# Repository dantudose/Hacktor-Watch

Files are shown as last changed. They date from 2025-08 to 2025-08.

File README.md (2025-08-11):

# Hacktor-Watch 2.0

Open-source power for apps, AI, and fearless hardware hacking!
Why just wear a smartwatch when you can hack it? Hacktor Watch 2.0 is your open-source playground on the wrist — powered by the dual-core ESP32-S3 with Wi-Fi and Bluetooth, rocking a bright 1.28" touch display, and loaded with goodies like a 6-axis IMU, mic, speaker, haptics, and fuel gauge. You get 32MB flash, 8MB PSRAM, USB-C charging, and a 200mAh LiPo to keep your creations running. Whether you’re building custom apps in Arduino or ESP-IDF, training tiny AI models, or turning it into a wearable IoT gadget, this is a smartwatch that’s down for any experiment you throw at it. 

And yes — it’s also sleek and stylish, so no matter how good or bad your code is, it will always look great on your wrist!

<div style='float:center'>
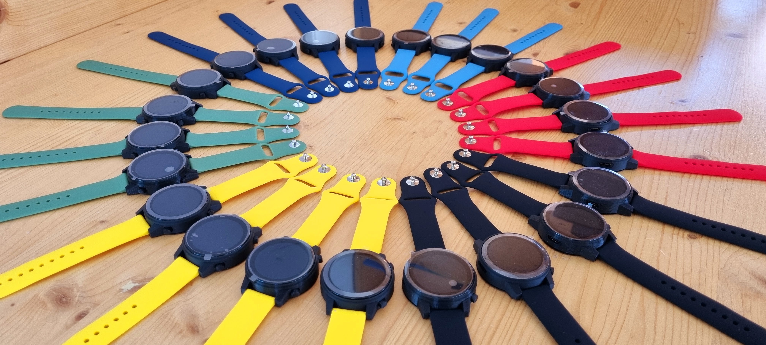
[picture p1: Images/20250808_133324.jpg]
   
  </div>

## Hardware Diagram &amp; features

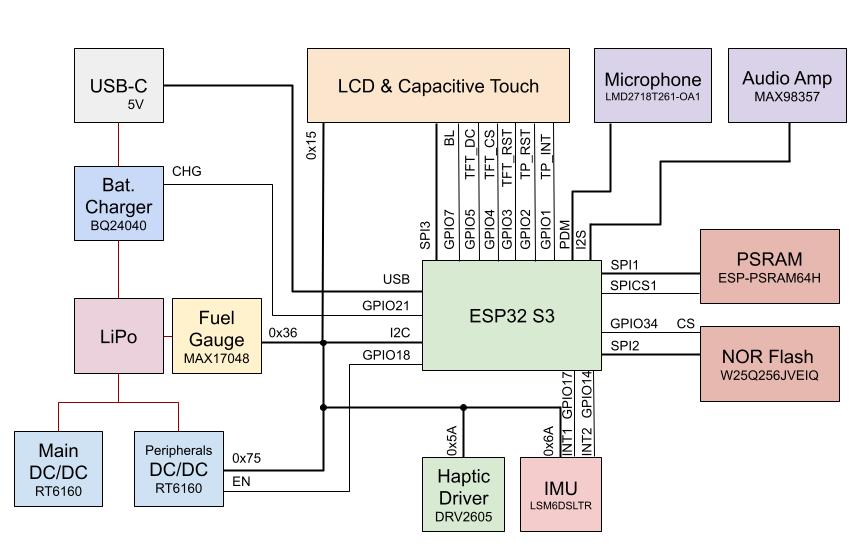
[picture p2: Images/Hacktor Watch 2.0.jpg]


<a href="https://docs.google.com/drawings/d/1u0_o-W6L3w2xveMWQQGLrzZhusZ90oDN8ES3exkrWA4/edit?usp=sharing">Hardware diagram.</a>

This is a open-hardware wearable based on the ESP32 microcontroller. It is fully Arduino-compatible and it comes with the following features:
* <a href="https://www.espressif.com/sites/default/files/documentation/esp32-s3_datasheet_en.pdf">ESP32-S3</a> processor (dual-core 240MHz, WiFI, BLE, 512kB SRAM and 4MB Flash)
* <a href="https://www.aliexpress.com/item/1005007293053050.html">GC9A01</a> 1.28 inch color LCD, 240 x 240 pixels with CST816T capacitive touch screen
* <a href="https://www.st.com/en/mems-and-sensors/lsm6dsl.html">LSM6DSLTR</a> 6-axis inertial sensor (accelerometer and gyroscope)
* <a href="https://www.winbond.com/hq/product/code-storage-flash-memory/serial-nor-flash/?__locale=en&partNo=W25Q256JV">W25Q256JVEIQ</a> 32MB external SPI Flash
* <a href="https://cdn-shop.adafruit.com/product-files/4677/4677_esp-psram64_esp-psram64h_datasheet_en.pdf">ESP-PSRAM64H</a> 8MB PSRAM
* <a href="https://www.ti.com/product/DRV2605/part-details/DRV2605YZFR">DRV2605YZFR</a> haptic driver
* <a href="https://jlcpcb.com/api/file/downloadByFileSystemAccessId/8586212537977618432">LMD2718T261-OA1</a> microphone
* <a href="https://www.analog.com/media/en/technical-documentation/data-sheets/max98357a-max98357b.pdf">MAX98357</a> I2S audio amplifier and speaker
* <a href="https://www.analog.com/media/en/technical-documentation/data-sheets/max17048-max17049.pdf">MAX17048</a> fuel gauge
* Dual <a href="https://www.richtek.com/m/Products/Switching%20Regulators/Buck-Boost%20Converter/RT6160A?sc_lang=en">RT6160</a> DC/DC PMIC (main power and peripherals)
* <a href="https://www.ti.com/lit/ds/symlink/bq24040.pdf?ts=1754753213993">BQ24040</a> LiPo charger
* 200mAh LiPo battery
* USB-C connector for charging and data

<div id="cover">
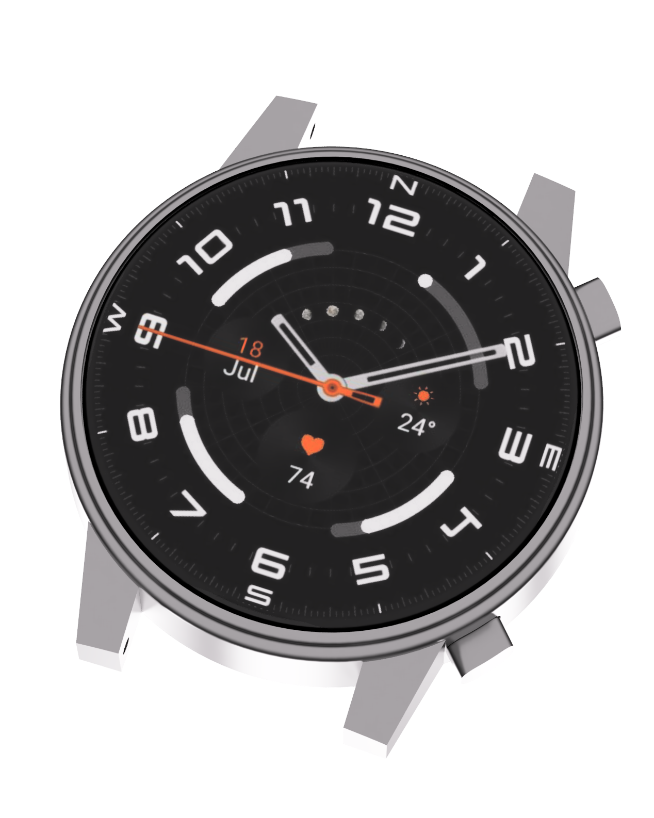
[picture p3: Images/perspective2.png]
   
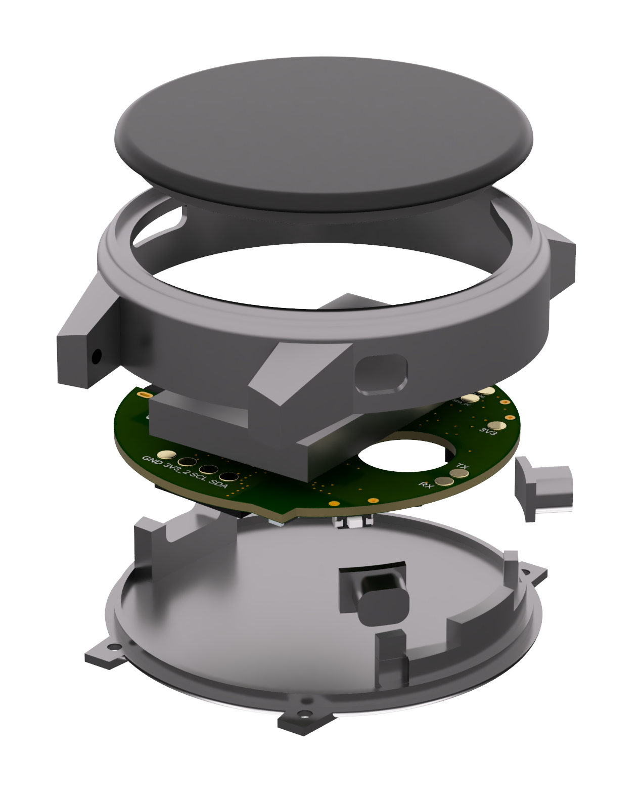
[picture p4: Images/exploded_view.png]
  
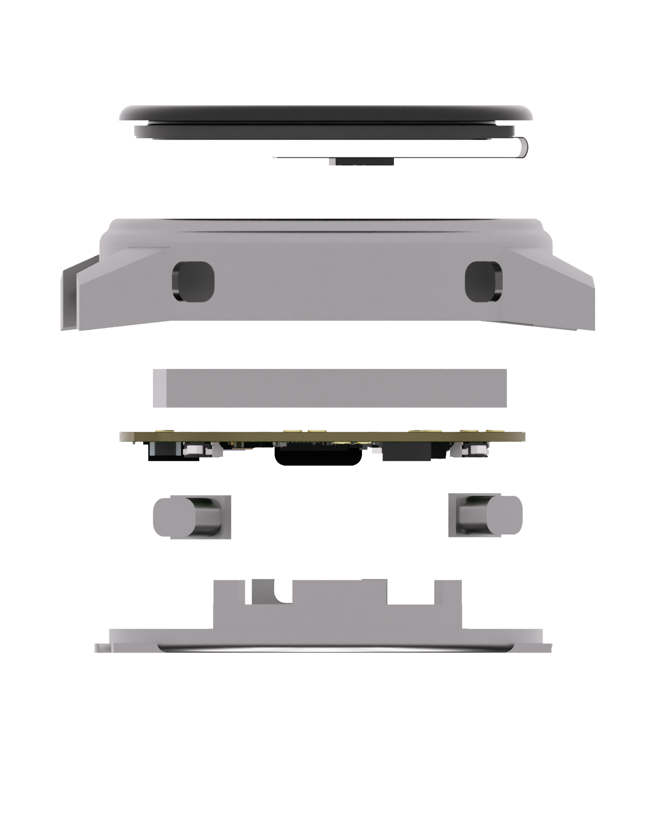
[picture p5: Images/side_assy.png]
   
</div>

## Repository Contents

* **/Hardware** - Schematic and hardware design files (Fusion360 & KiCAD)
* **/Images** - Images & diagrams
* **/Mechanical** - 3D files for the watch case

### Button Layout

 <div style='float:left'>
<table>
<thead>
  <tr>
    <th>Button</th>
    <th>ESP32 Pin</th>
  </tr></thead>
  <tbody>
  <tr>
    <td>BOOT</td>
    <td>IO0</td>
  </tr>
  <tr>
    <td>RESET</td>
    <td>EN</td>
  </tr>
  </tbody>
</table>
 </div>
<div style='float:right'>
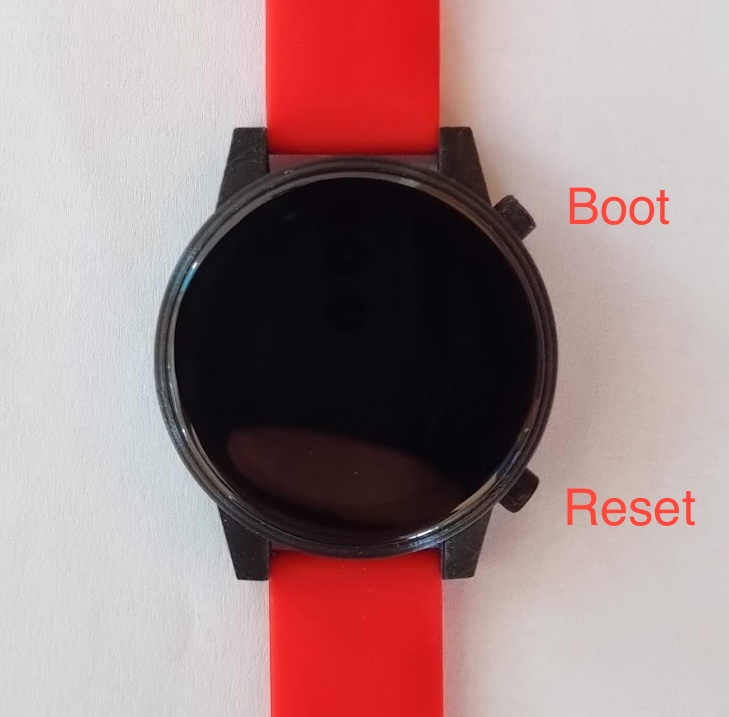
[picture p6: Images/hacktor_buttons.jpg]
   
  </div>

## Software Support
The watch supports Arduino and ESP-IDF programming. For a working NuttX port, check out <a href="https://github.com/radupascale/hectorwatch-nuttx">Radu Pascale's</a> repo. 

## License Information

HW design by <a href="https://github.com/radupascale">Radu Pascale</a>.

This product is _**open source**_! 

Please review the LICENSE file for license information. 

Distributed as-is; no warranty is given.

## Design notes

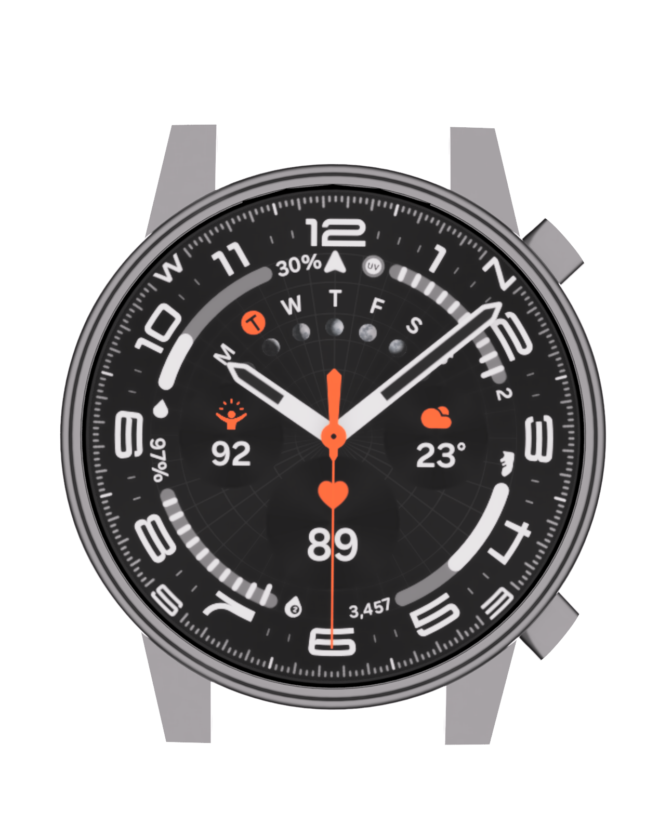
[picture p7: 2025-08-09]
Images/front_view.png

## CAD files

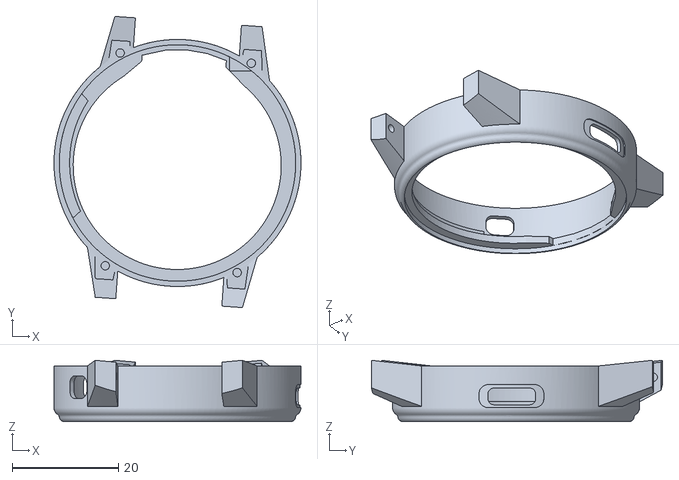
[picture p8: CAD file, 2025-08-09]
Mechanical/main_body.stl
46.5 x 54.8 x 11.6

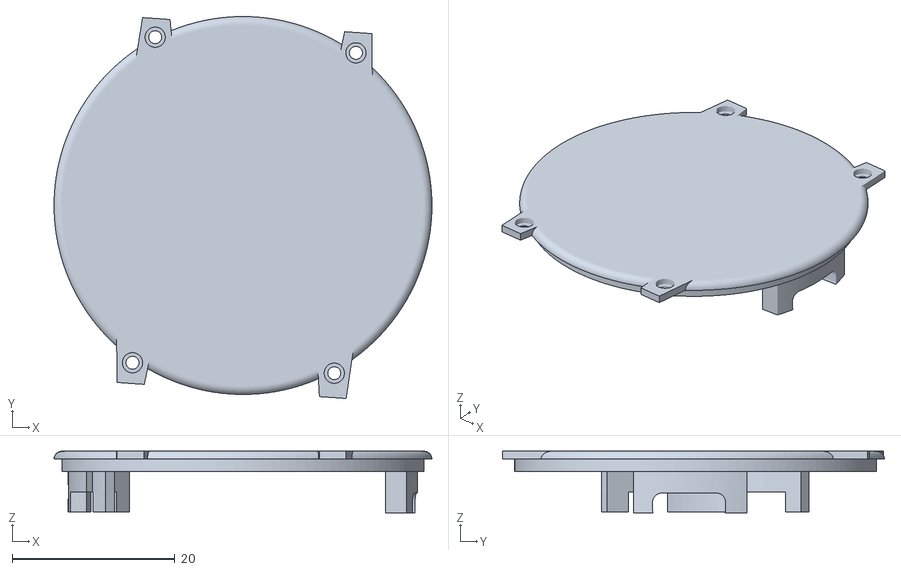
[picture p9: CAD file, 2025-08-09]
Mechanical/bottom_lid.stl
46.5 x 47.0 x 7.60

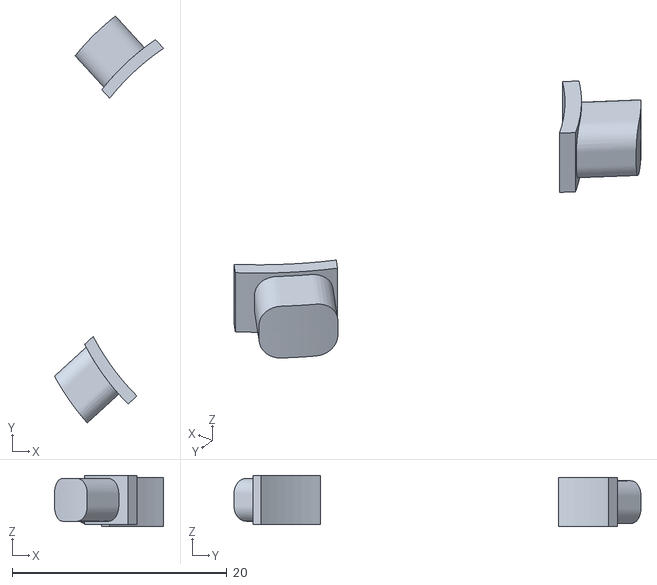
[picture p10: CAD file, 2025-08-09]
Mechanical/button_pushers.stl
10.2 x 37.9 x 4.78

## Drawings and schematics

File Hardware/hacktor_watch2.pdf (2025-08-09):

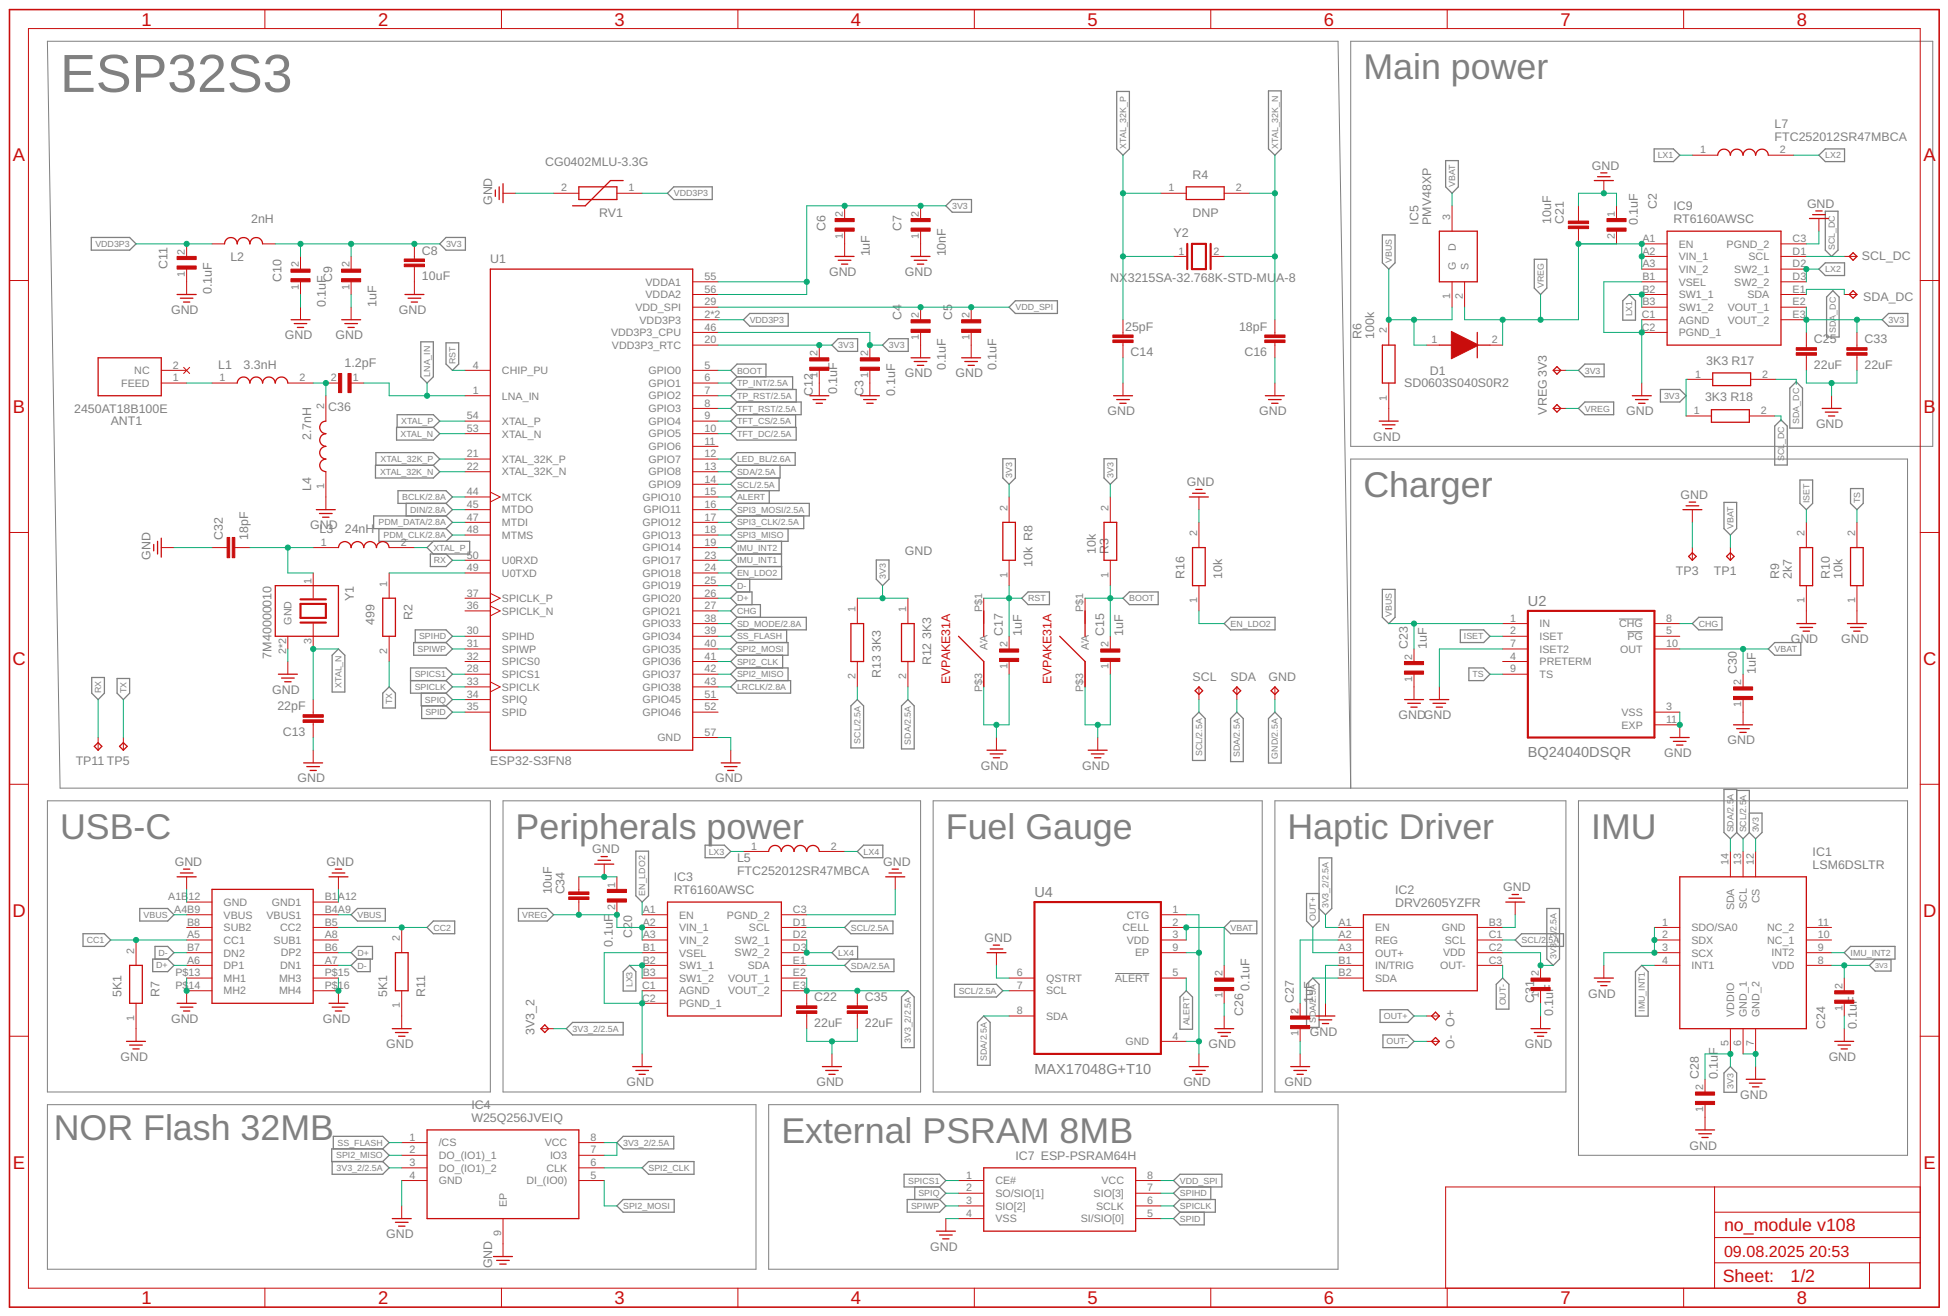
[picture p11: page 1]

XTAL_P | TFT_CS/2.5A 10 GPIO6
XTAL_N | TFT_DC/2.5A

XTAL_32K_P | LED_BL/2.6A 13 GPIO9

35 SPID | 52

SPIQ | SPIHD 6 SI/SIO[0] 5

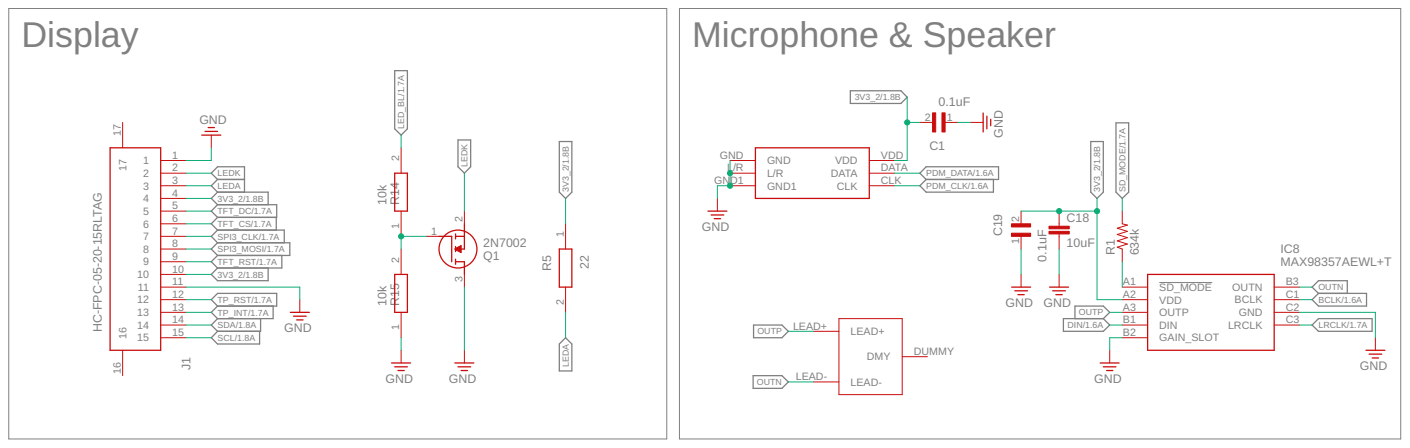
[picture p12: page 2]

0.1uF GND GND GND GND

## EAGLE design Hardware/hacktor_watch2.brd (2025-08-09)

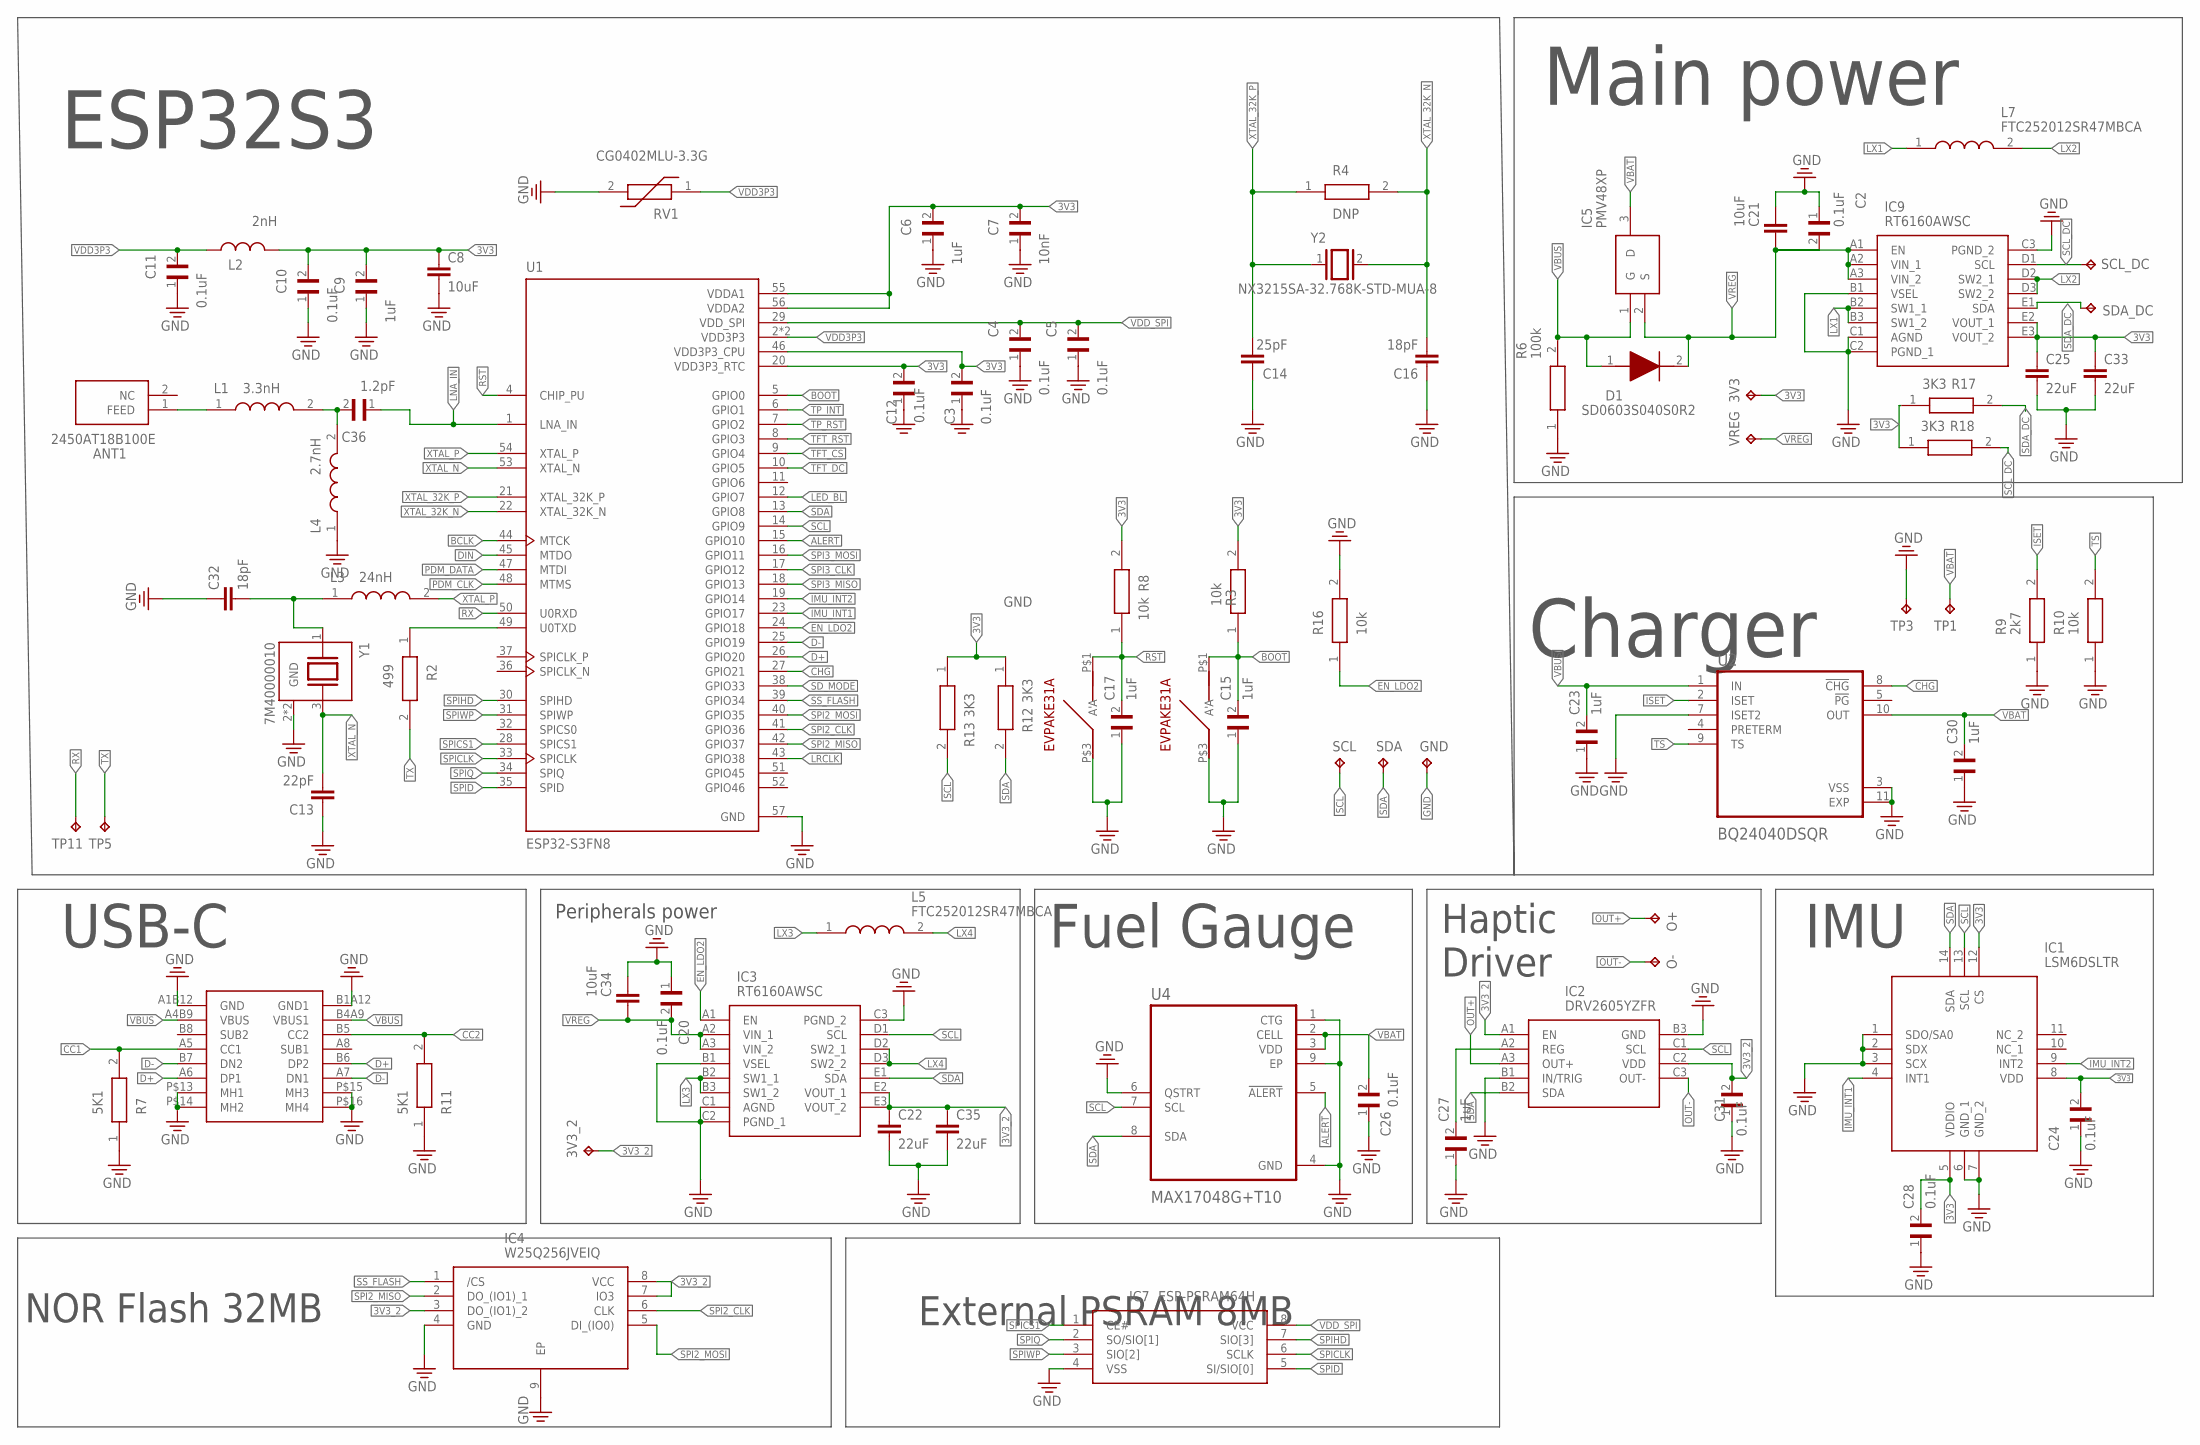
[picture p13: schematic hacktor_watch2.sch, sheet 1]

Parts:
3V3, 3V3_2: TPTP20R; TP20R
ANT1: 2450AT18B100E; ANTC3216X140N
C2, C3, C4, C5, C10, C11, C12, C20, C24, C26, C28, C31: 0.1uF; 0201
C6, C9, C15, C17, C23, C27, C30: 1uF; 0201
C7: 10nF; 0201
C8, C21, C34: 10uF; 0402
C13: 22pF; 0402
C14: 25pF; 0402
C16, C32: 18pF; 0402
C22, C25, C33, C35: 22uF; 0402
C36: 1.2pF; 0201
D1: SD0603S040S0R2; SD0603
GND: TPTP20R; TP20R
IC1: LSM6DSLTR
IC2: DRV2605YZFR; BGA9C50P3X3_144X144X62
IC3, IC9: RT6160AWSC; BGA15C40P3X5_140X230X60
IC4: W25Q256JVEIQ; SON127P800X600X80-9N
IC5: PMV48XP; SOT95P230X110-3N
IC7: ESP-PSRAM64H; SOIC127P600X175-8N
L1: 3.3nH; LQP15MN10NG02D
L2: 2nH; INDC1006X60N
L3: 24nH; LQP15MN10NG02D
L4: 2.7nH; LQP15MN10NG02D
L5, L7: FTC252012SR47MBCA; INDC2016X100N
O+: TPTP20R; TP20R
O-: TPTP20R; TP20R
R2: 499; 0201
R3, R8, R10, R16: 10k; 0201
R4: DNP; 0201
R6: 100k; 0201
R7, R11: 5K1; 0201
R9: 2k7; 0201
R12, R13, R17, R18: 3K3; 0201
RV1: CG0402MLU-3.3G; VARC1005X41N
SCL: TPTP20R; TP20R
SCL_DC: TPTP20R; TP20R
SDA: TPTP20R; TP20R
SDA_DC: TPTP20R; TP20R
TP1, TP3, TP5, TP11: TPTP20R; TP20R
U1: ESP32-S3FN8; QFN40P700X700X90-57N
U2: BQ24040DSQR; SON40P200X200X80-11N
U4: MAX17048G+T10; SON50P200X200X80-9N
U$1, U$3: EVPAKE31A
U$5: TYPE-C16PCB0.8073
VREG: TPTP20R; TP20R
Y1: 7M40000010; XTAL_7M40000010
Y2: NX3215SA-32.768K-STD-MUA-8; XTAL_NX3215SA-32.768K-STD-MUA-8

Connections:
3V3: 3V3.TP, C3.2, C6.2, C7.2, C8.1, C9.2, C10.2, C12.2, C24.2, C25.1, C28.2, C33.1, IC1.5 (VDDIO), IC1.8 (VDD), IC1.12 (CS), IC9.E2 (VOUT_1), IC9.E3 (VOUT_2), L2.2, R3.2, R8.2, R12.1, R13.1, R17.1, R18.1, U1.20 (VDD3P3_RTC), U1.46 (VDD3P3_CPU), U1.55 (VDDA1), U1.56 (VDDA2)
3V3_2: 3V3_2.TP, C22.1, C31.2, C35.1, IC2.A1 (EN), IC2.C2 (VDD), IC3.E2 (VOUT_1), IC3.E3 (VOUT_2), IC4.3 (DO_(IO1)_2), IC4.7 (IO3), IC4.8 (VCC); also elsewhere on the board
ALERT: U1.15 (GPIO10), U4.5 (!ALERT)
BCLK: U1.44 (MTCK); also elsewhere on the board
BOOT: C15.2, R3.1, U1.5 (GPIO0), U$1.P$1 (A)
CC1: R7.2, U$5.A5 (CC1)
CC2: R11.2, U$5.B5 (CC2)
CHG: U1.27 (GPIO21), U2.8 (!CHG)
D+: U1.26 (GPIO20), U$5.A6 (DP1), U$5.B6 (DP2)
D-: U1.25 (GPIO19), U$5.A7 (DN1), U$5.B7 (DN2)
DIN: U1.45 (MTDO); also elsewhere on the board
EN_LDO2: IC3.A1 (EN), R16.1, U1.24 (GPIO18)
GND: C2.1, C3.1, C4.1, C5.1, C6.1, C7.1, C8.2, C9.1, C10.1, C11.1, C12.1, C13.1, C14.1, C15.1, C16.1, C17.1, C20.1, C21.1, C22.2, C23.1, C24.1, C25.2, C26.1, C27.1, C28.1, C30.1, C31.1, C32.1, C33.2, C34.1, C35.2, GND.TP, IC1.1 (SDO/SA0), IC1.2 (SDX), IC1.3 (SCX), IC1.6 (GND_1), IC1.7 (GND_2), IC2.B1 (IN/TRIG), IC2.B3 (GND), IC3.B1 (VSEL), IC3.C1 (AGND), IC3.C2 (PGND_1), IC3.C3 (PGND_2), IC4.4 (GND), IC4.9 (EP), IC7.4 (VSS), IC9.B1 (VSEL), IC9.C1 (AGND), IC9.C2 (PGND_1), IC9.C3 (PGND_2), L4.1, R6.1, R7.1, R9.1, R10.1, R11.1, R16.2, RV1.2, TP3.TP, U1.57 (GND), U2.3 (VSS), U2.7 (ISET2), U2.11 (EXP), U4.1 (CTG), U4.4 (GND), U4.6 (QSTRT), U4.9 (EP), U$1.P$3 (A'), U$3.P$3 (A'), U$5.A1B12 (GND), U$5.B1A12 (GND1), U$5.P$13 (MH1), U$5.P$14 (MH2), U$5.P$15 (MH3), U$5.P$16 (MH4), Y1.2 (GND), Y1.4 (GND); also elsewhere on the board
IMU_INT1: IC1.4 (INT1), U1.23 (GPIO17)
IMU_INT2: IC1.9 (INT2), U1.19 (GPIO14)
ISET: R9.2, U2.2 (ISET)
LED_BL: U1.12 (GPIO7); also elsewhere on the board
LNA_IN: C36.1, U1.1 (LNA_IN)
LRCLK: U1.43 (GPIO38); also elsewhere on the board
LX1: IC9.B2 (SW1_1), IC9.B3 (SW1_2), L7.1
LX2: IC9.D2 (SW2_1), IC9.D3 (SW2_2), L7.2
LX3: IC3.B2 (SW1_1), IC3.B3 (SW1_2), L5.1
LX4: IC3.D2 (SW2_1), IC3.D3 (SW2_2), L5.2
unnamed: C32.2, L3.1, Y1.1
unnamed: ANT1.1 (FEED), L1.1
unnamed: C36.2, L1.2, L4.2
unnamed: R2.1, U1.49 (U0TXD)
unnamed: C27.2, IC2.A2 (REG)
OUT+: IC2.A3 (OUT+), O+.TP
OUT-: IC2.C3 (OUT-), O-.TP
PDM_CLK: U1.48 (MTMS); also elsewhere on the board
PDM_DATA: U1.47 (MTDI); also elsewhere on the board
RST: C17.2, R8.1, U1.4 (CHIP_PU), U$3.P$1 (A)
RX: TP11.TP, U1.50 (U0RXD)
SCL: IC1.13 (SCL), IC2.C1 (SCL), IC3.D1 (SCL), R13.2, SCL.TP, U1.14 (GPIO9), U4.7 (SCL); also elsewhere on the board
SCL_DC: IC9.D1 (SCL), R18.2, SCL_DC.TP
SDA: IC1.14 (SDA), IC2.B2 (SDA), IC3.E1 (SDA), R12.2, SDA.TP, U1.13 (GPIO8), U4.8 (SDA); also elsewhere on the board
SDA_DC: IC9.E1 (SDA), R17.2, SDA_DC.TP
SD_MODE: U1.38 (GPIO33); also elsewhere on the board
SPI2_CLK: IC4.6 (CLK), U1.41 (GPIO36)
SPI2_MISO: IC4.2 (DO_(IO1)_1), U1.42 (GPIO37)
SPI2_MOSI: IC4.5 (DI_(IO0)), U1.40 (GPIO35)
SPI3_CLK: U1.17 (GPIO12); also elsewhere on the board
SPI3_MISO: U1.18 (GPIO13)
SPI3_MOSI: U1.16 (GPIO11); also elsewhere on the board
SPICLK: IC7.6 (SCLK), U1.33 (SPICLK)
SPICS1: IC7.1 (CE#), U1.28 (SPICS1)
SPID: IC7.5 (SI/SIO[0]), U1.35 (SPID)
SPIHD: IC7.7 (SIO[3]), U1.30 (SPIHD)
SPIQ: IC7.2 (SO/SIO[1]), U1.34 (SPIQ)
SPIWP: IC7.3 (SIO[2]), U1.31 (SPIWP)
SS_FLASH: IC4.1 (/CS), U1.39 (GPIO34)
TFT_CS: U1.9 (GPIO4); also elsewhere on the board
TFT_DC: U1.10 (GPIO5); also elsewhere on the board
TFT_RST: U1.8 (GPIO3); also elsewhere on the board
TP_INT: U1.6 (GPIO1); also elsewhere on the board
TP_RST: U1.7 (GPIO2); also elsewhere on the board
TS: R10.2, U2.9 (TS)
TX: R2.2, TP5.TP
VBAT: C26.2, C30.2, IC5.3 (D), TP1.TP, U2.10 (OUT), U4.2 (CELL), U4.3 (VDD)
VBUS: C23.2, D1.1 (A), IC5.1 (G), R6.2, U2.1 (IN), U$5.A4B9 (VBUS), U$5.B4A9 (VBUS1)
VDD3P3: C11.2, L2.1, RV1.1, U1.2 (VDD3P3), U1.3 (VDD3P3)
VDD_SPI: C4.2, C5.2, IC7.8 (VCC), U1.29 (VDD_SPI)
VREG: C2.2, C20.2, C21.2, C34.2, D1.2 (K), IC3.A2 (VIN_1), IC3.A3 (VIN_2), IC5.2 (S), IC9.A1 (EN), IC9.A2 (VIN_1), IC9.A3 (VIN_2), VREG.TP
XTAL_32K_N: C16.2, R4.2, U1.22 (XTAL_32K_N), Y2.2
XTAL_32K_P: C14.2, R4.1, U1.21 (XTAL_32K_P), Y2.1
XTAL_N: C13.2, U1.53 (XTAL_N), Y1.3 (2)
XTAL_P: L3.2, U1.54 (XTAL_P)

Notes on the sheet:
ESP32S3
Main power
Charger
USB-C
Peripherals power
Fuel Gauge
IMU
Haptic Driver
NOR Flash 32MB
External PSRAM 8MB

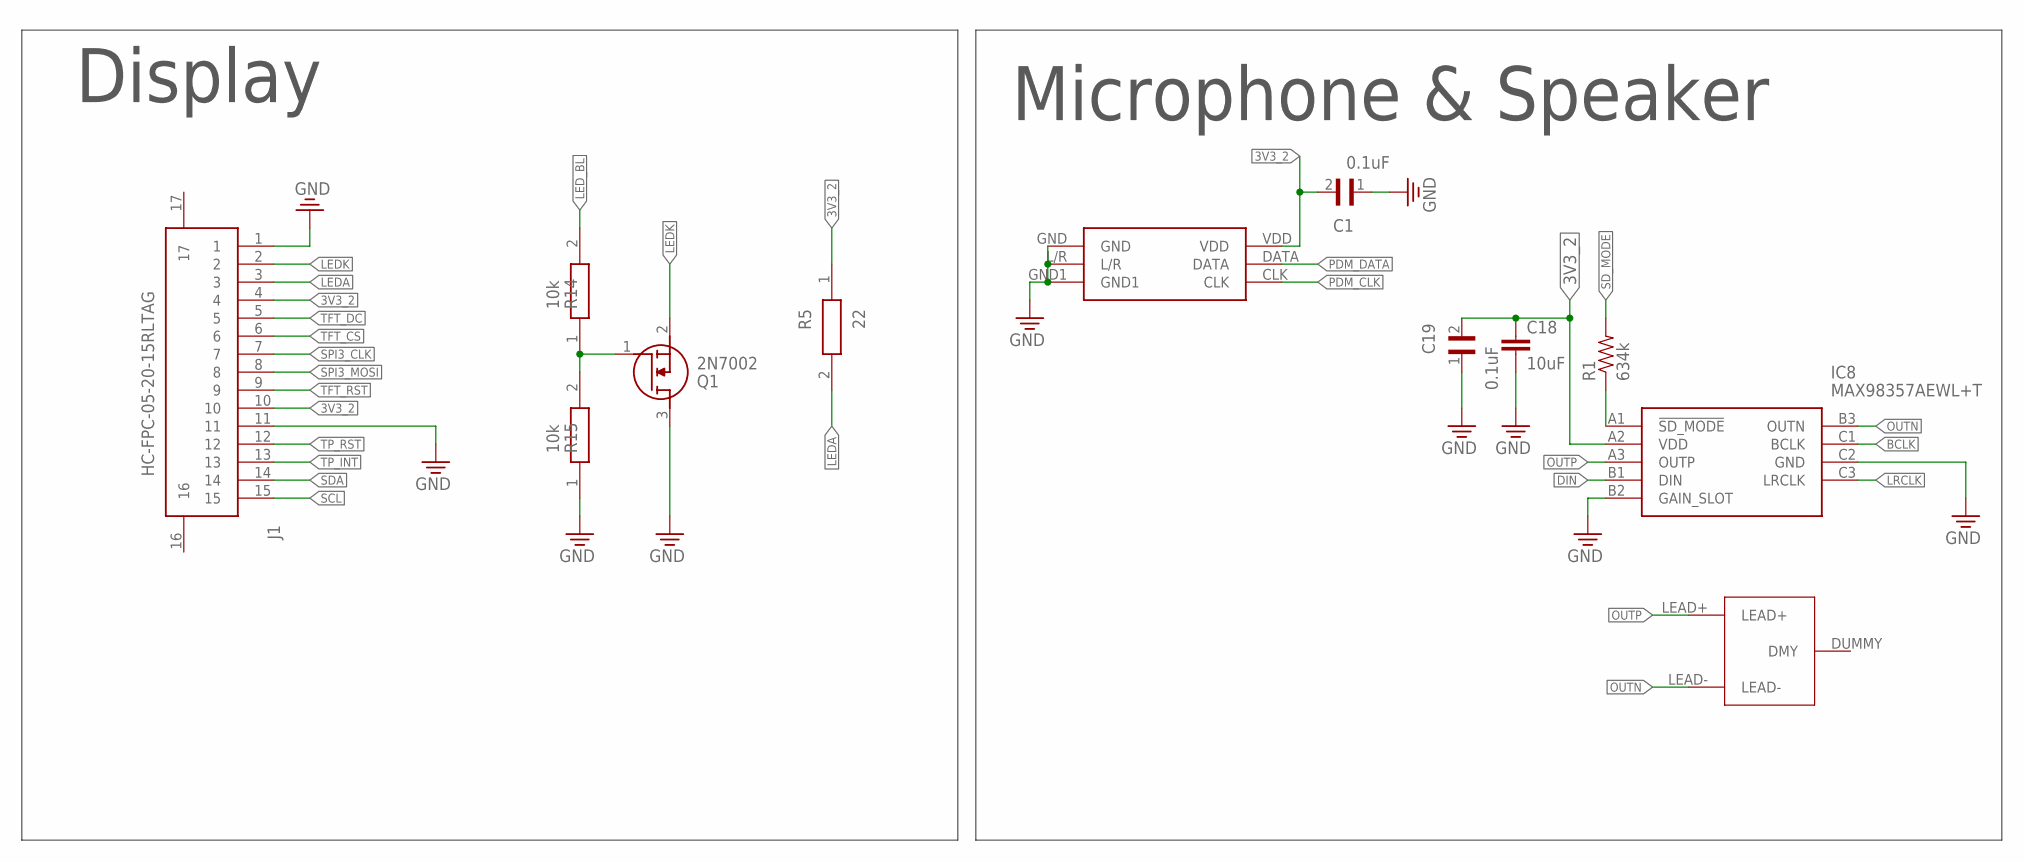
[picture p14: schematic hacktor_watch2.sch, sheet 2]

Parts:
C1, C19: 0.1uF; 0201
C18: 10uF; 0402
IC8: MAX98357AEWL+T; BGA9C40P3X3_144X135X69
J1: HC-FPC-05-20-15RLTAG
Q1: 2N7002; SOT96P240X120-3N
R1: 634k; 0402
R5: 22; 0201
R14, R15: 10k; 0201
U$4: TE054003-1
U$6: LMD2718T261-OA1

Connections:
3V3_2: C1.2, C18.1, C19.2, IC8.A2 (VDD), J1.4, J1.10, R5.1, U$6.VDD; also elsewhere on the board
BCLK: IC8.C1 (BCLK); also elsewhere on the board
DIN: IC8.B1 (DIN); also elsewhere on the board
GND: C1.1, C18.2, C19.1, IC8.B2 (GAIN_SLOT), IC8.C2 (GND), J1.1, J1.11, Q1.3 (D), R15.1, U$6.GND, U$6.GND1, U$6.L/R; also elsewhere on the board
LEDA: J1.3, R5.2
LEDK: J1.2, Q1.2 (S)
LED_BL: R14.2; also elsewhere on the board
LRCLK: IC8.C3 (LRCLK); also elsewhere on the board
unnamed: IC8.A1 (!SD_MODE), R1.1
unnamed: Q1.1 (G), R14.1, R15.2
OUTN: IC8.B3 (OUTN), U$4.LEAD-
OUTP: IC8.A3 (OUTP), U$4.LEAD+
PDM_CLK: U$6.CLK; also elsewhere on the board
PDM_DATA: U$6.DATA; also elsewhere on the board
SCL: J1.15; also elsewhere on the board
SDA: J1.14; also elsewhere on the board
SD_MODE: R1.2; also elsewhere on the board
SPI3_CLK: J1.7; also elsewhere on the board
SPI3_MOSI: J1.8; also elsewhere on the board
TFT_CS: J1.6; also elsewhere on the board
TFT_DC: J1.5; also elsewhere on the board
TFT_RST: J1.9; also elsewhere on the board
TP_INT: J1.13; also elsewhere on the board
TP_RST: J1.12; also elsewhere on the board

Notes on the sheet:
Display
Microphone & Speaker

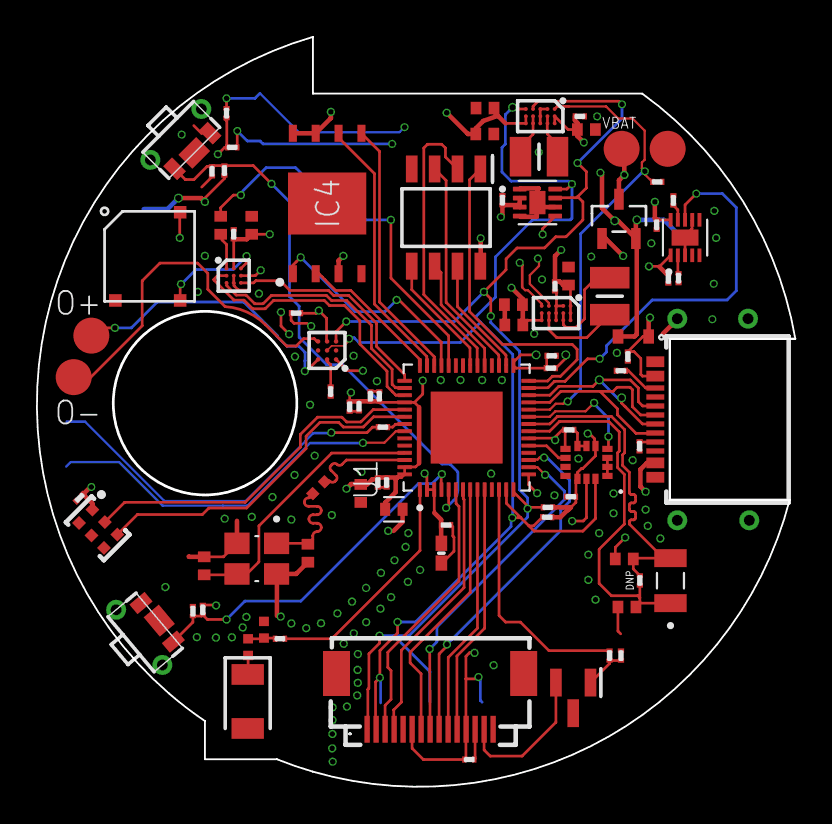
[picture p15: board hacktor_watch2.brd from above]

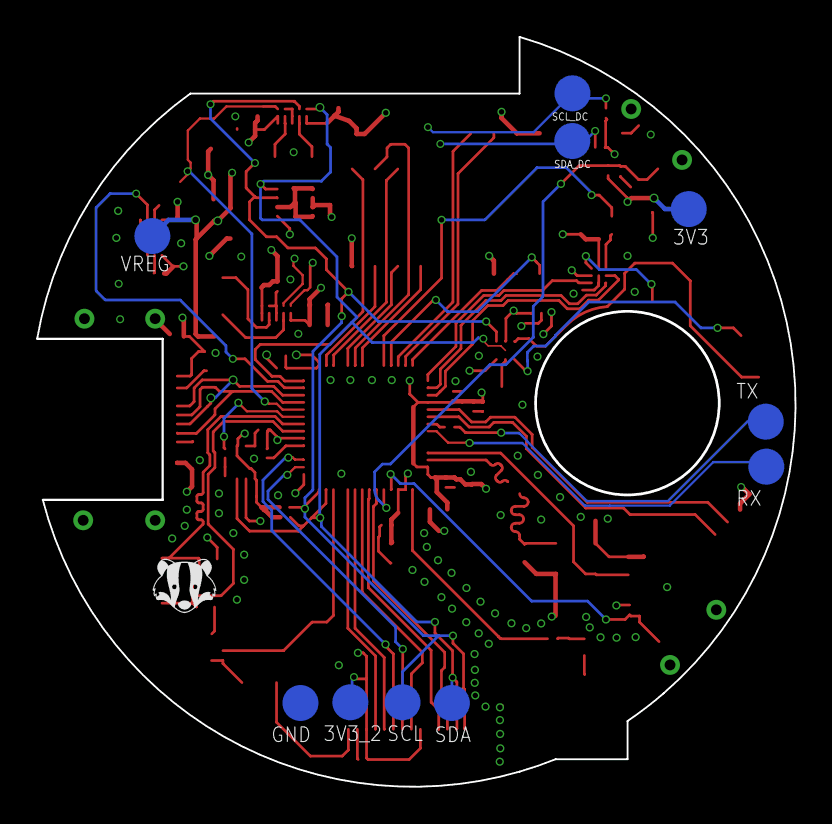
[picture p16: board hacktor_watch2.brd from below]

Board: 4 copper layers, 42.1 x 41.7 mm, 96 parts (10 on the bottom side), 73 nets.
